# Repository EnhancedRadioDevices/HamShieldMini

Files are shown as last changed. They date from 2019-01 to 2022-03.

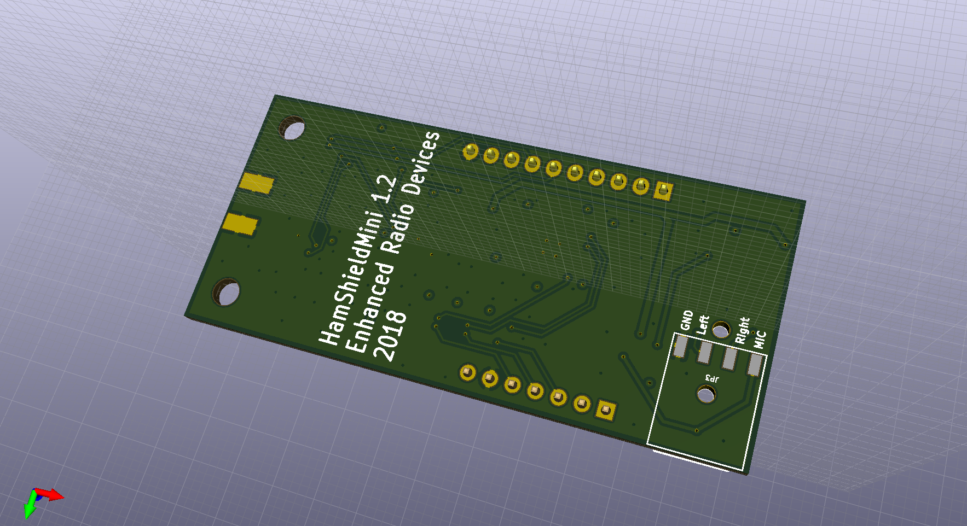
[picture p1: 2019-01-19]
HamShieldMini1.2_files/HamShieldMini_back.png

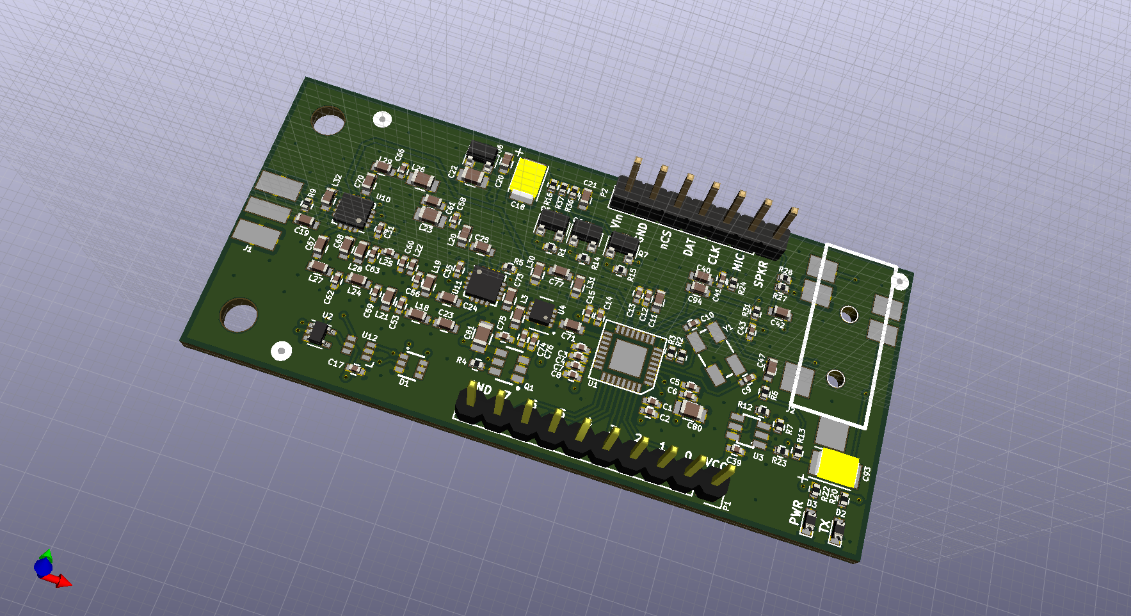
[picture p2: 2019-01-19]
HamShieldMini1.2_files/HamShieldMini_front.png

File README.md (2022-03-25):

HamShieldMini1.1 Hardware

You can purchase HamShield Mini (as well as our larger variants or LoRa version) at http://www.enhancedradio.com/

These are the hardware design files for the HamShieldMini1.1 electronics.

These hardware files were created with KiCAD. 
You may need the KiCAD libraries available here: https://github.com/mogar/KiCAD_libs
When opening these projects in KiCAD, you may need to change the path to the libraries from the above link.
This can be done in preferences->libraries in both the schematic editor and the layout editor.
Make sure the libraries noted there point to wherever you put the above KiCAD_libs repo.

# Arduino Connections

To use the HamShieldMini with an Arduino, you can use our standard HamShield library: 

https://github.com/EnhancedRadioDevices/HamShield

The pinout should be:

    1	- SPKR - Arduino Pin A2
    2	- MIC  - Arduino Pin D3
    3	- CLK/SCLK  - Arduino Pin A5
    4	- DAT/SDIO  - Arduino Pin A4
    5	- nCS/nSEN  - Arduino Pin A1
    6	- GND  - Arduino Pin GND
    7	- VCC  - Arduino Pin 5V

# Raspberry Pi Connections

To use the HamShieldMini with a Raspberry Pi, you can use our HamShieldPy library: 

https://github.com/EnhancedRadioDevices/HamShieldPy

The pinout should be:

    2	- MIC  - RPi Pin 12 (wiringPi1, PWM0)
    3	- CLK  - RPi Pin 15 (wiringPi3)
    4	- nCS  - RPi Pin 11 (wiringPi0)
    5	- DAT  - RPi Pin 13 (wiringPi2)
    6	- GND  - RPi Pin 6 (GND)
    7	- VCC  - RPi Pin 1 (3.3V)

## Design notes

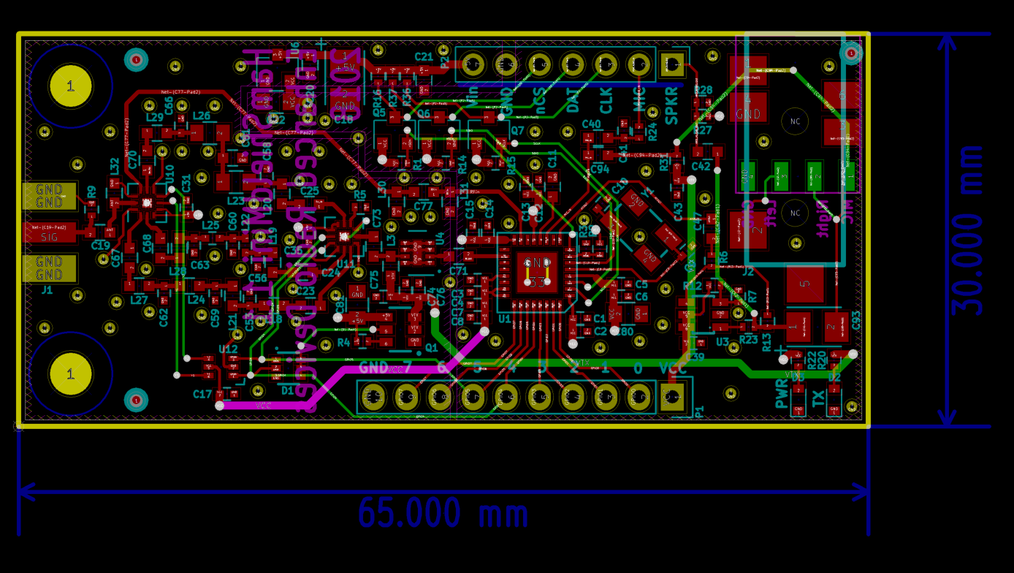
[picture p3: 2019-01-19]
HamShieldMini1.2_files/HamShieldMini_layout.png

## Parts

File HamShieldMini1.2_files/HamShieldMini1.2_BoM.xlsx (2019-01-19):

Id | Designator | Package | Quantity | Designation | Mfg | Mfg PN | Distributor | Dist PN | Substitution Mfg | Substitution Mfg PN | Substitution Dist PN
1 | U11,U10 | QFN16-3x3mm-0.5mmP | 2 | PE42440MLBB-Z | pSemi | PE42440MLBB-Z | DigiKey | 1046-1038-1-ND
2 | J2 | SJ-43514-SMT-TR | 1 | SJ-43514-SMT-TR | CUI | SJ-43514-SMT-TR | DigiKey | CP-43514SJDKR-ND
3 | U1 | QFN32-5x5 | 1 | AU1846 | Auctus | AU1846 | Auctus | AU1846
4 | U3 | SOT23-6 | 1 | AD8591 | Analog Devices | AD8591ARTZ-REEL7 | DigiKey | AD8591ARTZ-REEL7DKR-ND
5 | P1 | Pin_Header_Straight_1x10 | 1 | CONN_01X10 | DNP | DNP | DNP | DNP
6 | P2 | Pin_Header_Straight_1x7 | 1 | CONN_01X7 | DNP | DNP | DNP | DNP
7 | C20 | C_0603 | 1 | 4.7u | Yageo | CC0603KRX5R6BB475 | DigiKey | 311-1455-2-ND
8 | C1,C3,C5,C7,C12,C14 | C_0402 | 6 | 1n | Yageo | CC0402KRX7R9BB102 | DigiKey | 311-1036-6-ND
9 | C2,C4,C6,C8,C17,C31,C35,C39,C43,C75,C76 | C_0402 | 11 | 0u1 | Taiyo-Yuden | LMK105BJ104KV-F | DigiKey | 587-1227-1-ND
10 | C9,C10,C15 | C_0402 | 3 | 10p | Murata | GJM1555C1H100JB01D | DigiKey | 490-3113-2-ND
11 | C13 | C_0402 | 1 | 1u | Murata | GRM155R61A105KE15J | DigiKey | 490-6298-2-ND
12 | C19,C23,C24,C25,C67,C73,C68,C70,C71,C77 | C_0603 | 10 | 100p | Johanson | 251R14S101JV4T | DigiKey | 712-1310-2-ND
13 | C40,C94,C42,C47,C21,C11 | C_0603 | 6 | 2u2 | Taiyo-Yuden | JMK107BJ225KAHT | DigiKey | 587-3386-6-ND
14 | C41 | C_0402 | 1 | 15n | Samsung | CL05B153KB5VPNC | DigiKey | 1276-6846-6-ND
15 | C56,C63 | C_0402 | 2 | 14p | AVX | 04025U140GAT2A | Mouser | 581-04025U140GAT2A
16 | C59 | C_0402 | 1 | 8.2p | Murata | GJM1555C1H8R2CB01D | DigiKey | 490-3110-2-ND
17 | C60 | C_0402 | 1 | 15p | Murata | GJM1555C1H150JB01D | DigiKey | 490-3117-2-ND
18 | C74 | C_0402 | 1 | 10n | Taiyo-Yuden | UMK105B7103KV-F | DigiKey | 587-2238-2-ND
19 | R2 | R_0402 | 1 | 0 | Vishay Dale | CRCW04020000Z0ED | DigiKey | 541-0.0JDKR-ND
20 | R36,R37,R1,R14,R15,R16,R12,R13,R4,R6,R7,R9 | R_0402 | 12 | 10k | TE Connectivity | 1622826-4 | DigiKey | A106045TR-ND
21 | R23 | R_0402 | 1 | 13.3 | Vishay Dale | CRCW040213R3FKED | DigiKey | 541-13.3LDKR-ND
22 | R24 | R_0402 | 1 | 1.47k | Yageo | RC0402FR-071K47L | DigiKey | YAG3038TR-ND
23 | R27,R28 | R_0402 | 2 | 100k | Vishay Dale | CRCW0402100KJNED | DigiKey | 541-100KJDKR-ND
24 | R31 | R_0402 | 1 | 2k | Vishay Dale | CRCW04022K00JNED | DigiKey | 541-2.0KJDKR-ND
25 | Q1 | SC-74 | 1 | NTGD1100L | ON Semi | NTGD1100L | DigiKey | NTGD1100LT1GOSTR-ND
26 | R5 | R_0402 | 1 | 49.9 | Yageo | RC0402FR-0749R9L | DigiKey | 311-49.9LRTR-ND
27 | D1 | SOT-363 | 1 | BAS40TW | Diodes Inc. | BAS40TW | DigiKey | BAS40TW-FDITR-ND
28 | C58,C66 | C_0402 | 2 | 20p | Murata | GJM1555C1H200JB01D | DigiKey | 490-3120-2-ND
29 | U12 | SC-70-6 | 1 | NC7WZ14 | Fairchild Semi | NC7WZ14 | DigiKey | NC7WZ14P6XTR-ND
30 | C61 | C_0603 | 1 | 24p | Murata | GQM1885C1H240GB01D | DigiKey | 490-8131-2-ND
31 | L18,L27 | C_0603 | 2 | 24n | Murata | LQW18AN24NJ00D | DigiKey | 490-6878-2-ND
32 | L19,L28 | C_0603 | 2 | 47n | Bourns | CW160808-47NJ | DigiKey | CW160808-47NJTR-ND
33 | L21,L24 | C_0603 | 2 | 33n | Murata | LQW18AN33NJ00D | DigiKey | 490-1175-2-ND
34 | C53,C62 | C_0402 | 2 | 7p | Murata | GJM1555C1H7R0CB01D | DigiKey | 490-3107-2-ND
35 | L22,L25 | C_0402 | 2 | 75n | Murata | LQW15AN75NJ00D | DigiKey | 490-6843-1-ND
36 | L23,L26 | C_0805 | 2 | 120n | Bourns | PM0805-R12K-RC | DigiKey | M8464TR-ND
37 | C18,C93 | C1210P | 2 | 47u | AVX | TAJB476K010RNJ | DigiKey | 478-1693-2-ND
38 | U4 | LFCSP-8-1EP_2x3mm_Pitch0.5mm | 1 | ADL5530 | Analog Devices | ADL5530 | DigiKey | ADL5530ACPZ-R7CT-ND
39 | L30,L31,L32 | C_0603 | 3 | DNP
40 | C22,C80 | C_0805 | 2 | 10u | Murata | GRM21BR61E106KA73L | DigiKey | 490-5523-2-ND
41 | L3 | C_0603 | 1 | 470n | Abracon | AISC-0603F-R47J-T | DigiKey | 535-12525-1-ND
42 | L20,L29 | C_0603 | 2 | 82n | Bourns | PM0603-82NJ-RC | DigiKey | M8491TR-ND
43 | C81 | C_0805 | 1 | 22u | Samsung | CL21A226MQQNNNE | DigiKey | 1276-1100-2-ND
44 | J1 | SMA-EDGE-HandSolder | 1 | DNP | Linx | CONSMA003.062 | DigiKey | CONSMA003.062-ND
45 | R3 | R_0402 | 1 | DNP
46 | D2,D3 | D_0603 | 2 | LED | Lite-On | LTST-C190KGKT | DigiKey | 160-1435-2-ND
47 | R20,R22 | R_0402 | 2 | 330 | Yageo | RC0402JR-07330RL | DigiKey | 311-330JRTR-ND
48 | JP3 | PinHeader_SMT_rightAngle_0.1inPitch_4pos | 1 | DNP
49 | Q5,Q6,Q7 | SOT-23 | 3 | BSS138 | Fairchild Semi | BSS138 | DigiKey | BSS138TR-ND
50 | U6 | SOT-23 | 1 | AP2125N-3.3TRG1 | Diodes Inc. | AP2125N-3.3TRG1 | DigiKey | AP2125N-3.3TRG1DITR-ND
51 | Y1 | CRYSTAL-SMD-5X3 | 1 | 12.8MHz | CTS | 405C11A12M80000 | DigiKey | CTX957DKR-ND
52 | U2 | SC70-5 | 1 | NC7SZ86 | ON Semi | NC7SZ86P5X | DigiKey | NC7SZ86P5XCT-ND

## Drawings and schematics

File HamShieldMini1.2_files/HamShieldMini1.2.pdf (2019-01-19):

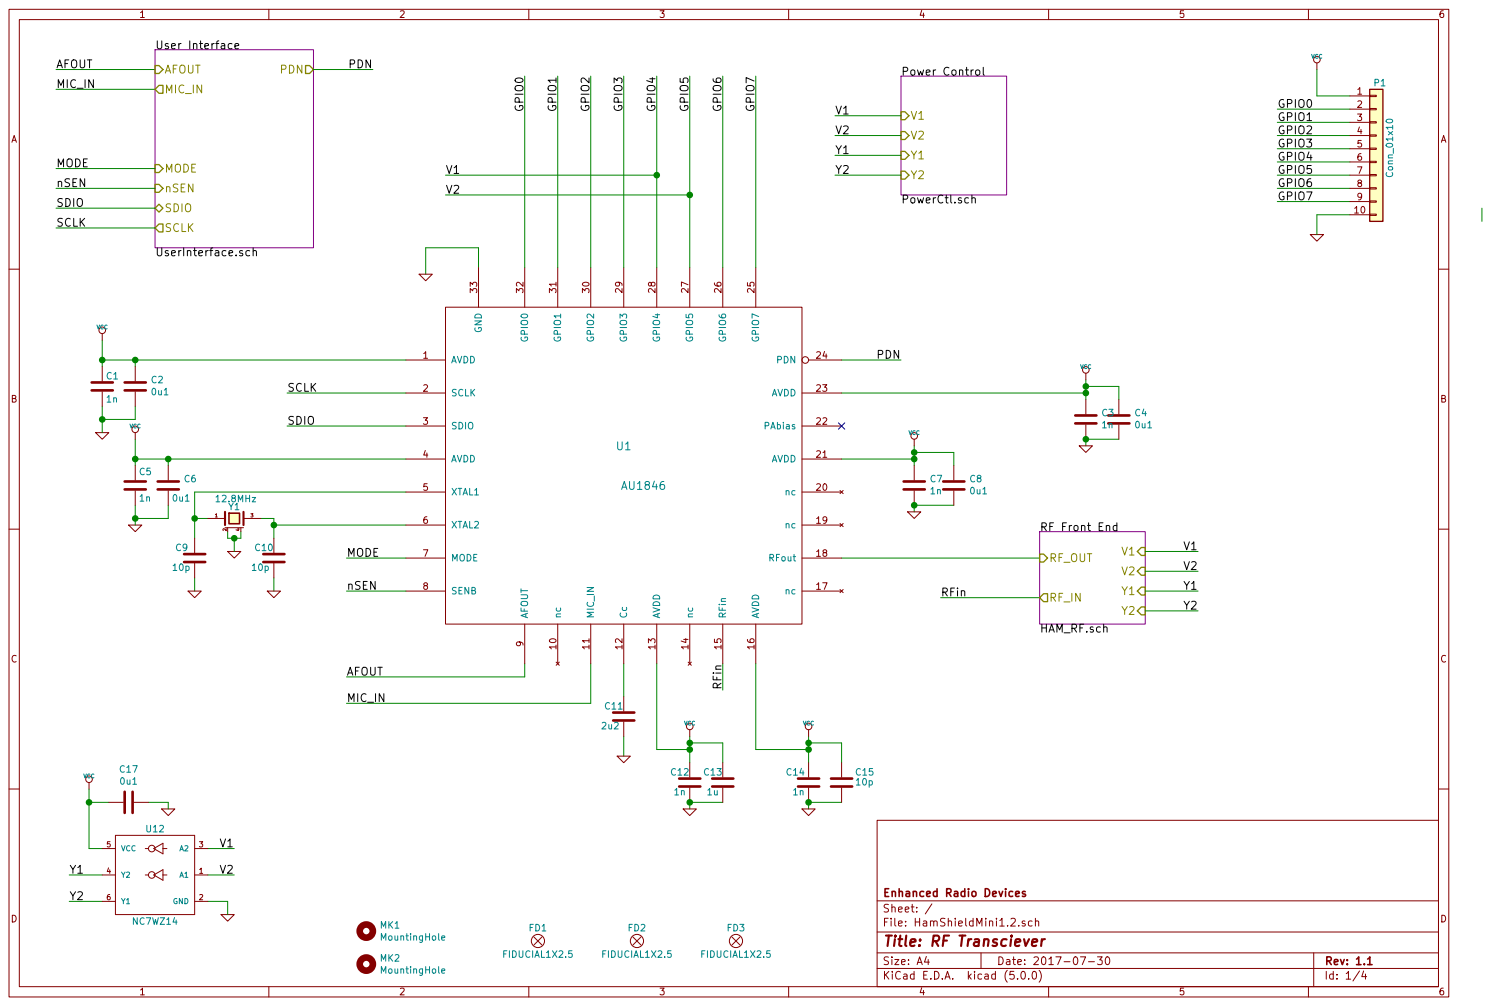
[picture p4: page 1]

Id: 1/4 Title: RF Transciever File: HamShieldMini1.2.sch Sheet: / Enhanced Radio Devices

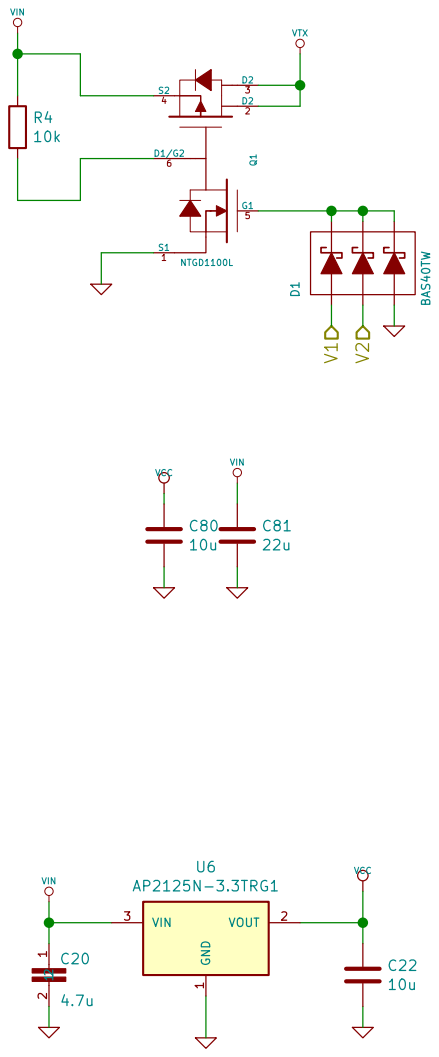
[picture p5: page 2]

Id: 2/4 Title: Power Control File: PowerCtl.sch Sheet: /Power Control/ Enhanced Radio Devices

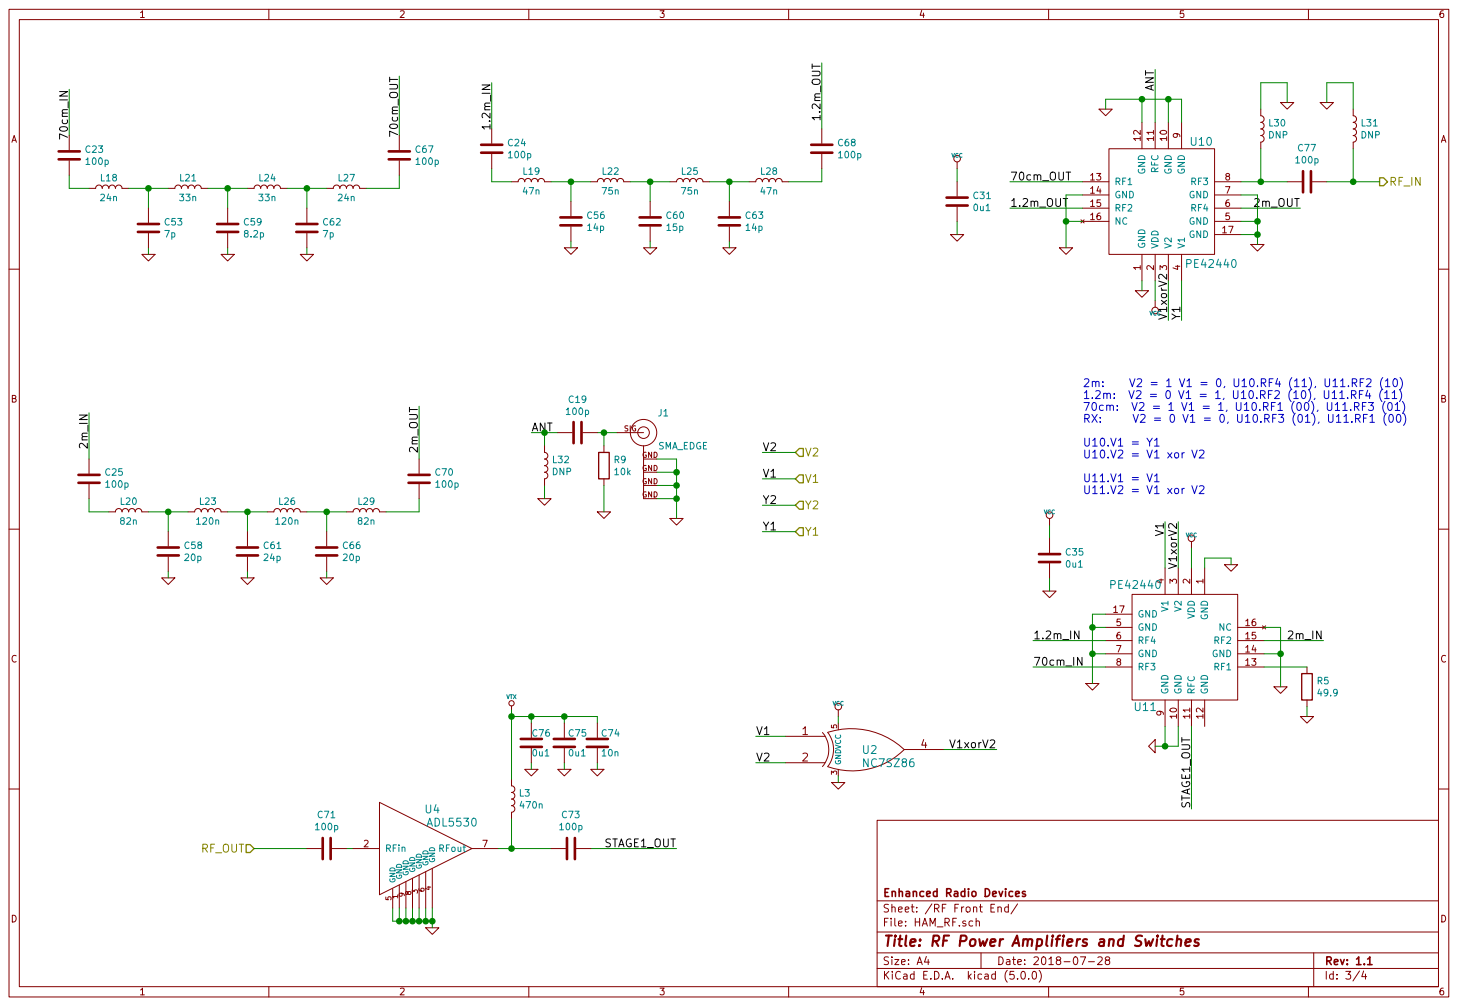
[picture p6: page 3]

1 GND 10 RFC 11 GND 12 RF1 13 GND 14 RF2 15 NC 16 GND 17 VDD

File: HAM_RF.sch Sheet: /RF Front End/ Enhanced Radio Devices

Id: 3/4 Title: RF Power Amplifiers and Switches

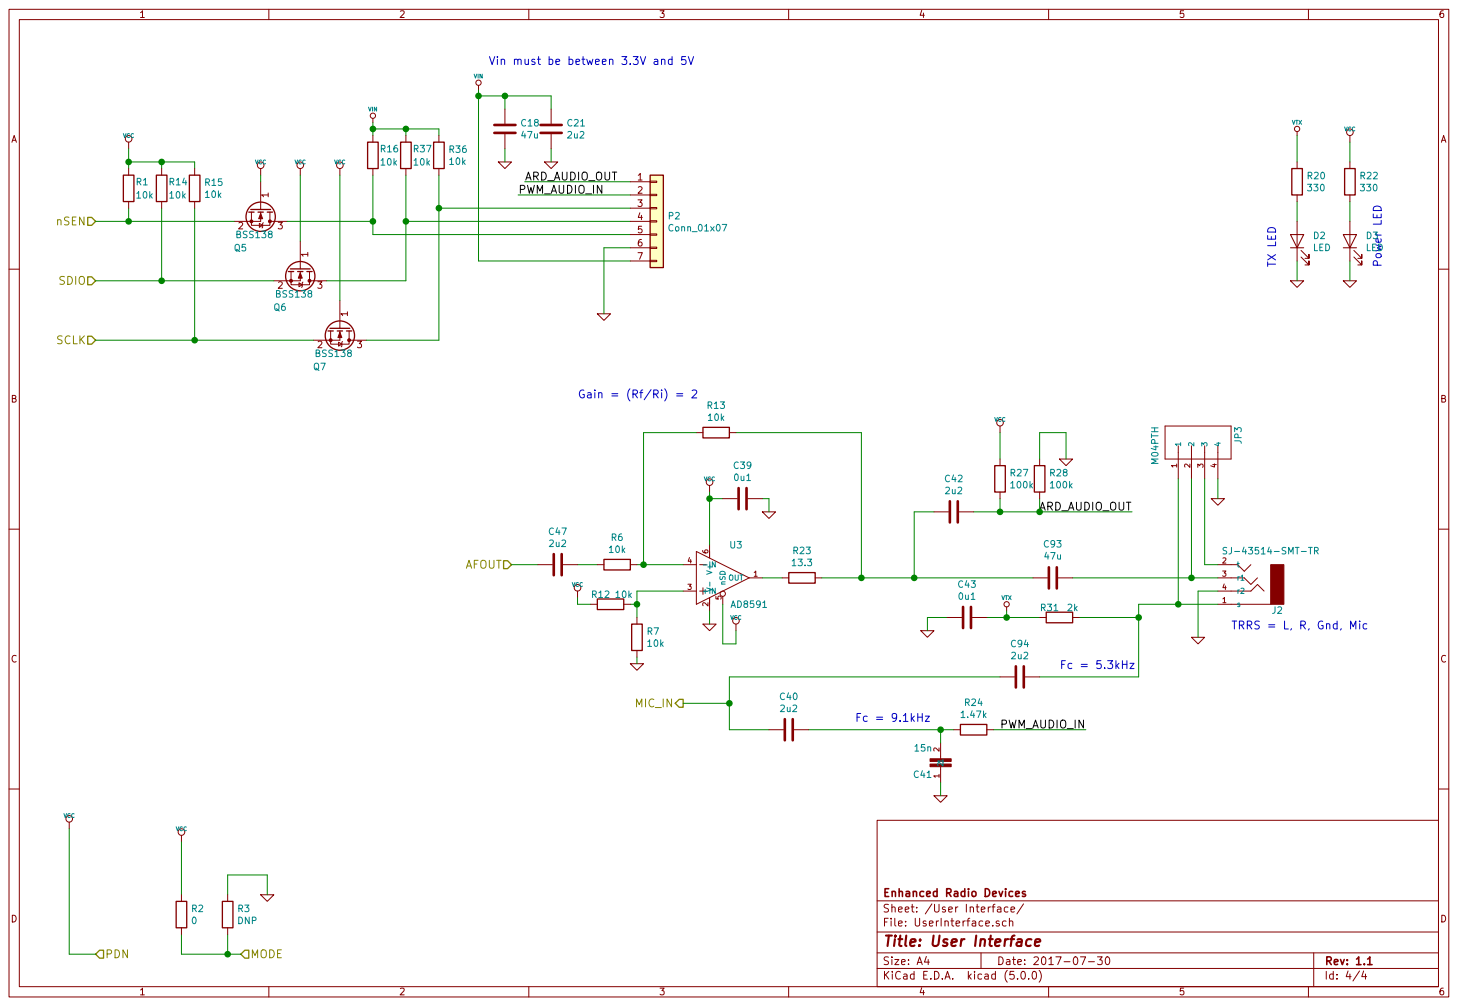
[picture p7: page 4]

Id: 4/4 Title: User Interface

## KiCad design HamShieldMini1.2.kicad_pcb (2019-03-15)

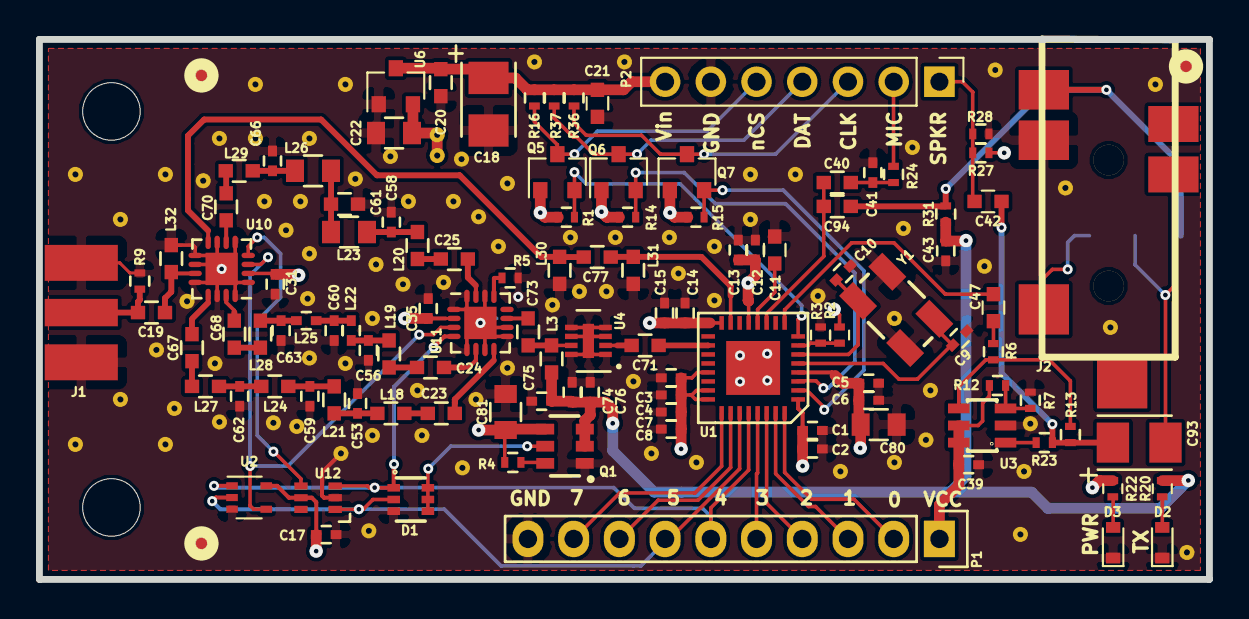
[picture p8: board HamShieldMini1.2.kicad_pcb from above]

Board: 4 copper layers, 65.0 x 30.0 mm, 118 parts (1 on the bottom side), 71 nets.

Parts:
C1, C3, C5, C7, C12, C14: 1n; C_0402
C2, C4, C6, C8, C17, C31, C35, C39, C43, C75, C76: 0u1; C_0402
C9, C10, C15: 10p; C_0402
C11, C21, C40, C42, C47, C94: 2u2; C_0603
C13: 1u; C_0402
C18, C93: 47u; C1210P
C19, C23, C24, C25, C67, C68, C70, C71, C73, C77: 100p; C_0603
C20: 4.7u; C_0603
C22, C80: 10u; C_0805
C41: 15n; C_0402
C53, C62: 7p; C_0402
C56, C63: 14p; C_0402
C58, C66: 20p; C_0402
C59: 8.2p; C_0402
C60: 15p; C_0402
C61: 24p; C_0603
C74: 10n; C_0402
C81: 22u; C_0805
D1: BAS40TW; SOT-363
D2, D3: LED; D_0603
FD1, FD2, FD3: FIDUCIAL1X2.5; SparkFun-FIDUCIAL-1X2.5
J1: SMA_EDGE; SMA-EDGE-HandSolder
J2: SJ-43514-SMT-TR
JP3: M04PTH; PinHeader_SMT_rightAngle_0.1inPitch_4pos
L3: 470n; C_0603
L18, L27: 24n; C_0603
L19, L28: 47n; C_0603
L20, L29: 82n; C_0603
L21, L24: 33n; C_0603
L22, L25: 75n; C_0402
L23, L26: 120n; C_0805
L30, L31, L32: DNP; C_0603
MK1, MK2: MountingHole; MountingHole_3.2mm_M3
P1: Conn_01x10; Pin_Header_Straight_1x10
P2: Conn_01x07; Pin_Header_Straight_1x07_Pitch2.54mm
Q1: NTGD1100L; SC-74
Q5, Q6, Q7: BSS138; SOT-23
R1, R4, R6, R7, R9, R12, R13, R14, R15, R16, R36, R37: 10k; R_0402
R2: 0; R_0402
R3: DNP; R_0402
R5: 49.9; R_0402
R20, R22: 330; R_0402
R23: 13.3; R_0402
R24: 1.47k; R_0402
R27, R28: 100k; R_0402
R31: 2k; R_0402
U1: AU1846; QFN32-5x5
U2: NC7SZ86; SOT-353_SC-70-5
U3: AD8591; SOT23-6
U4: ADL5530; LFCSP-8-1EP_2x3mm_Pitch0.5mm
U6: AP2125N-3.3TRG1; SOT-23
U10, U11: PE42440; QFN-16-1EP_3x3mm_Pitch0.5mm
U12: NC7WZ14; SC-70-6
Y1: 12.8MHz; CRYSTAL-SMD-5X3

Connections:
/AFOUT: C47.2, U1.9
/CLK: Q7.2, R15.2, U1.2
/DAT: Q6.2, R14.2, U1.3
/GPIO0: P1.2, U1.32
/GPIO1: P1.3, U1.31
/GPIO2: P1.4, U1.30
/GPIO3: P1.5, U1.29
/GPIO4: D1.1, P1.6, U1.28, U2.1, U11.4, U12.3
/GPIO5: D1.2, P1.7, U1.27, U2.2, U12.1
/GPIO6: P1.8, U1.26
/GPIO7: P1.9, U1.25
/MIC_IN: C40.2, C94.2, U1.11
/MODE: R2.2, R3.2, U1.7
/RF Front End/1.2m_IN: C24.1, U11.6
/RF Front End/1.2m_OUT: C68.1, U10.15
/RF Front End/2m_IN: C25.2, U11.15
/RF Front End/2m_OUT: C70.2, U10.6
/RF Front End/70cm_IN: C23.1, U11.8
/RF Front End/70cm_OUT: C67.1, U10.13
/RF Front End/ANT: C19.2, L32.1, U10.11
/RF Front End/RF_OUT: C71.1, U1.18
/RF Front End/STAGE1_OUT: C73.2, U11.11
/RF Front End/V1xorV2: U2.4, U10.3, U11.3
/RFin: C77.2, L31.2, U1.15
/User Interface/ARD_AUDIO_OUT: C42.1, P2.1, R27.2, R28.2
/User Interface/PWM_AUDIO_IN: P2.2, R24.1
/Y1: U10.4, U12.4
/nCS: Q5.2, R1.2, U1.8
GND: C1.1, C2.1, C3.1, C4.1, C5.1, C6.1, C7.1, C8.1, C9.1, C10.1, C11.1, C12.1, C13.1, C14.1, C15.1, C17.1, C18.2, C20.2, C21.2, C22.2, C31.2, C35.2, C39.1, C41.1, C43.2, C53.2, C56.2, C58.2, C59.2, C60.2, C61.2, C62.2, C63.2, C66.2, C74.2, C75.2, C76.2, C80.2, C81.2, D1.3, D2.1, D3.1, J1.GND, J2.4, JP3.4, L30.1, L31.1, L32.2, P1.10, P2.6, Q1.1, R3.1, R5.2, R7.2, R9.2, R28.1, U1.33, U2.3, U3.2, U4.1, U4.3, U4.4, U4.5, U4.6, U4.8, U4.9, U6.1, U10.1, U10.5, U10.7, U10.9, U10.10, U10.12, U10.14, U10.16, U10.17, U11.1, U11.5, U11.7, U11.9, U11.10, U11.14, U11.16, U11.17, U12.2, Y1.2, Y1.4
unnamed: C9.2, U1.5, Y1.1
unnamed: C10.2, U1.6, Y1.3
unnamed: C11.2, U1.12
unnamed: C19.1, J1.SIG, R9.1
unnamed: C23.2, L18.1
unnamed: C24.2, L19.1
unnamed: C25.1, L20.1
unnamed: C40.1, C41.2, R24.2
unnamed: C42.2, C93.1, R13.1, R23.1
unnamed: C47.1, R6.2
unnamed: C53.1, L18.2, L21.1
unnamed: C56.1, L19.2, L22.1
unnamed: C58.1, L20.2, L23.1
unnamed: C59.1, L21.2, L24.1
unnamed: C60.1, L22.2, L25.1
unnamed: C61.1, L23.2, L26.1
unnamed: C62.1, L24.2, L27.1
unnamed: C63.1, L25.2, L28.1
unnamed: C66.1, L26.2, L29.1
unnamed: C67.2, L27.2
unnamed: C68.2, L28.2
unnamed: C70.1, L29.2
unnamed: C71.2, U4.2
unnamed: C73.1, L3.2, U4.7
unnamed: C77.1, L30.2, U10.8
unnamed: C93.2, J2.3, JP3.2
unnamed: C94.1, J2.1, JP3.1, R31.1
unnamed: D1.4, D1.5, D1.6, Q1.5
unnamed: D2.2, R20.2
unnamed: D3.2, R22.2
unnamed: J2.2, JP3.3
unnamed: P2.3, Q7.3, R36.2
unnamed: P2.4, Q6.3, R37.2
unnamed: P2.5, Q5.3, R16.2
unnamed: Q1.6, R4.2
unnamed: R5.1, U11.13
unnamed: R7.1, R12.1, U3.3
unnamed: R6.1, R13.2, U3.4
unnamed: R23.2, U3.1
VCC: C1.2, C2.2, C3.2, C4.2, C5.2, C6.2, C7.2, C8.2, C12.2, C13.2, C14.2, C15.2, C17.2, C22.1, C31.1, C35.1, C39.2, C80.1, P1.1, Q5.1, Q6.1, Q7.1, R1.1, R2.1, R12.2, R14.1, R15.1, R22.1, R27.1, U1.1, U1.4, U1.13, U1.16, U1.21, U1.23, U1.24, U2.5, U3.5, U3.6, U6.2, U10.2, U11.2, U12.5
VIN: C18.1, C20.1, C21.1, C81.1, P2.7, Q1.4, R4.1, R16.1, R36.1, R37.1, U6.3
VTX: C43.1, C74.1, C75.1, C76.1, L3.1, Q1.2, Q1.3, R20.1, R31.2

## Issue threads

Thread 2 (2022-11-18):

stackup question

dotemup, 2022-11-18:
Hi,

I'm looking to get some of these printed and assembled via pcbway for a project.

There is a stackup question though, in the drawing on the gerbers there is a typo for the stackup. Is the standard pcbway stackup okay https://www.pcbway.com/multi-layer-laminated-structure.html?

Or if required for correct impedance control what is the correct core as it is noted to be 47mil?

mogar, 2022-11-25:
If you clone the repo and open the KiCAD project, you should be able to see the stackup listed on the Cmts.User layer. It was designed around the stackup available from OSHPark for 4-layer boards (as of several years ago, haven't checked since). Here's the stackup:

                Four Layer PCB
 mil           solder resist          +/-0.2mil
1.4 mil     1 oz copper
6.7 mil     FR408 prepreg       +/-.67mil
0.7 mil     0.5 oz copper
47 mil      FR408 core            +/-4.7mil
0.7 mil     0.5 oz copper
6.7 mil     FR408 prepreg       +/-.67mil
1.4 mil     1 oz copper
1 mil        solder resist           +/-0.2mil

No copper thieving on any layer.
Note split plane on layer 3.

Closed 2022-11-25.

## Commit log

2019-01-19 adding all files
    [HAM_RF.sch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]
2019-03-15 unify pin naming scheme
    [HamShieldMini1.2.kicad_pcb, HamShieldMini1.2.sch, UserInterface.sch]
2019-06-20 CLK Pin 3 goes to Arduino A5, not A6
    Probably was a typo, fixed. Bad joo joo for noobs when there's a pin error in README.md :-)
2019-06-20 Fixed nCS and DAT pin numbers
